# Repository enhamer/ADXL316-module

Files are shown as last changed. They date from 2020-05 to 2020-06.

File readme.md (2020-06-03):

<!---
#**============================================================================
#**
#**                    Accelerometer ADXL316 MODULE
#**                  THIS REPOSITORY IS PART OF THE ENHAMER
#**
#** TITLE:           ADXL-316 PCB (Circuit, Hardware)
#**
#** AUTHOR:          Marcin J. Kraśny
#**
#**					 Advanced Biological Imaging Laboratory
#**                  School of Physics
#**                  College of Science and Engineering
#**                  National University of Ireland, Galway
#**
#** SOURCE URL       https://github.com/enhamer/enhamer
#** COPYRIGHT        © 2015-2020 M.J.Kraśny
#** LICENSE          CERN-OHL-P v2
#** CREDITS          NEMESIS - Novel Energy Materials, Engineering Science 
#**                  and Integrated Systems
#**                  Department of Mechanical Engineering
#**					 University of Bath, UK
#**
#**============================================================================
#**============================================================================
-->

# ADXL316 module
Part of:
**Energy Harvesting Measurement Rig (ENHAMER)**

*A System for Characterisation of Piezoelectric Materials and Associated Electronics for Vibration Powered Energy Harvesting Devices*

>For detailed **Information, Manuals and Description** please go to [**ENHAMER**](https://github.com/enhamer/enhamer/).

Assembled module mounted on acrylic holder:
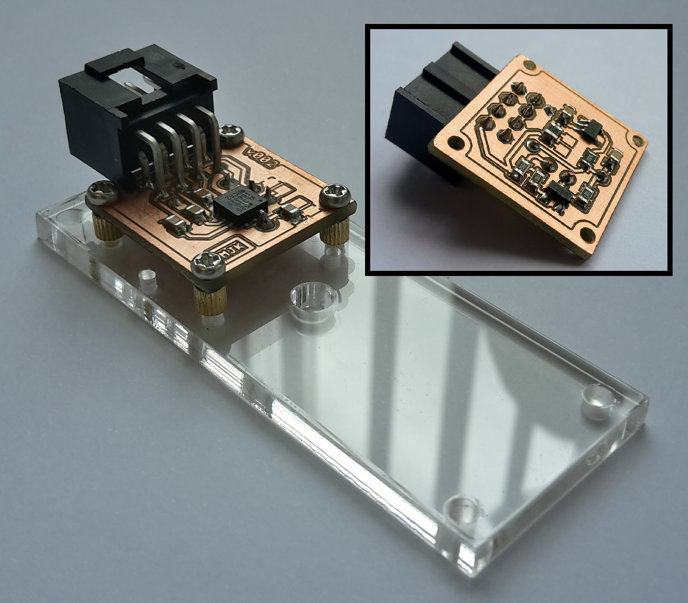
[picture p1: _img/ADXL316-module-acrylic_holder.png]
ADXL316 module


## Design software used
[EAGLE CAD](https://www.autodesk.com/products/eagle/overview)

# License
Copyright © 2015-2020 Marcin J. Kraśny

This work is licensed under the [CERN-OHL-P v2](LICENSE/cern_ohl_p_v2.txt); 
[CERN Open Hardware Licence version 2](https://cern.ch/cern-ohl).

You may redistribute and modify this documentation and make products
using it under the terms of the CERN-OHL-P v2 (<https:/cern.ch/cern-ohl>).
This documentation is distributed WITHOUT ANY EXPRESS OR IMPLIED WARRANTY INCLUDING OF MERCHANTABILITY, SATISFACTORY QUALITY AND FITNESS FOR A PARTICULAR PURPOSE. 
Please see the CERN-OHL-P v2 for applicable conditions.

# SOURCE
[https://github.com/enhamer](https://github.com/enhamer/enhamer/)

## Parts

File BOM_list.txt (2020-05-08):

Partlist

Exported from ADXL316-module.brd at 08/05/2020 17:02

EAGLE Version 9.5.1 Copyright (c) 1988-2019 Autodesk, Inc.

Assembly variant: 

Part     Value             Package          Library                Position (mil)        Orientation

ACC      ADXL316           QFN24-4X4_MJK    _Accelerometers_Krasny (522 390)             R270
C1       100nF             0805             _passive_Krasny        (675 519)             R0
C2       33pF              0805             _passive_Krasny        (675 603)             R0
C3       10nF              0805             _passive_Krasny        (420 141)             R180
C4       10nF              0805             _passive_Krasny        (420 243)             R180
C5       10nF              0805             _passive_Krasny        (339 342)             R180
C6       1uF               0805             _passive_Krasny        (369 213)             MR270
C7       1uF               0805             _passive_Krasny        (663 279)             MR270
L1       2u2H              0805             _passive_Krasny        (450 372)             MR270
R1       ns_0R             0805             _passive_Krasny        (369 372)             MR270
R2       0R                0805             _passive_Krasny        (570 372)             MR90
R3       1k                0805             _passive_Krasny        (450 645)             MR90
R4       20k               0805             _passive_Krasny        (369 645)             MR90
R5       1k                0805             _passive_Krasny        (663 561)             MR270
R6       ns_0R             0805             _passive_Krasny        (483 621)             R0
SV1                        MA04-2           con-lstb               (147.47244 392.15748) MR90
T1       BC847             SOT23            transistor             (550 641)             MR180
U1       ADP151AUJZ-3.3-R7 SOT95P280X100-5N _PowerSupply_Krasny    (504 207)             MR180

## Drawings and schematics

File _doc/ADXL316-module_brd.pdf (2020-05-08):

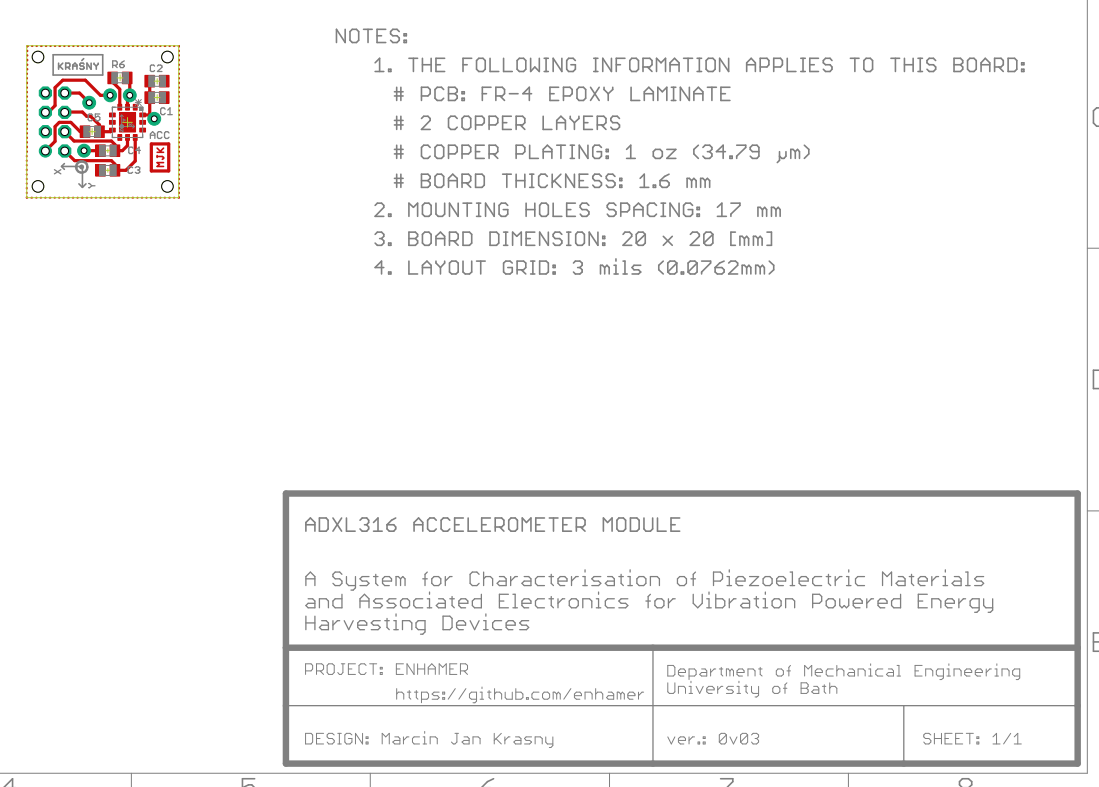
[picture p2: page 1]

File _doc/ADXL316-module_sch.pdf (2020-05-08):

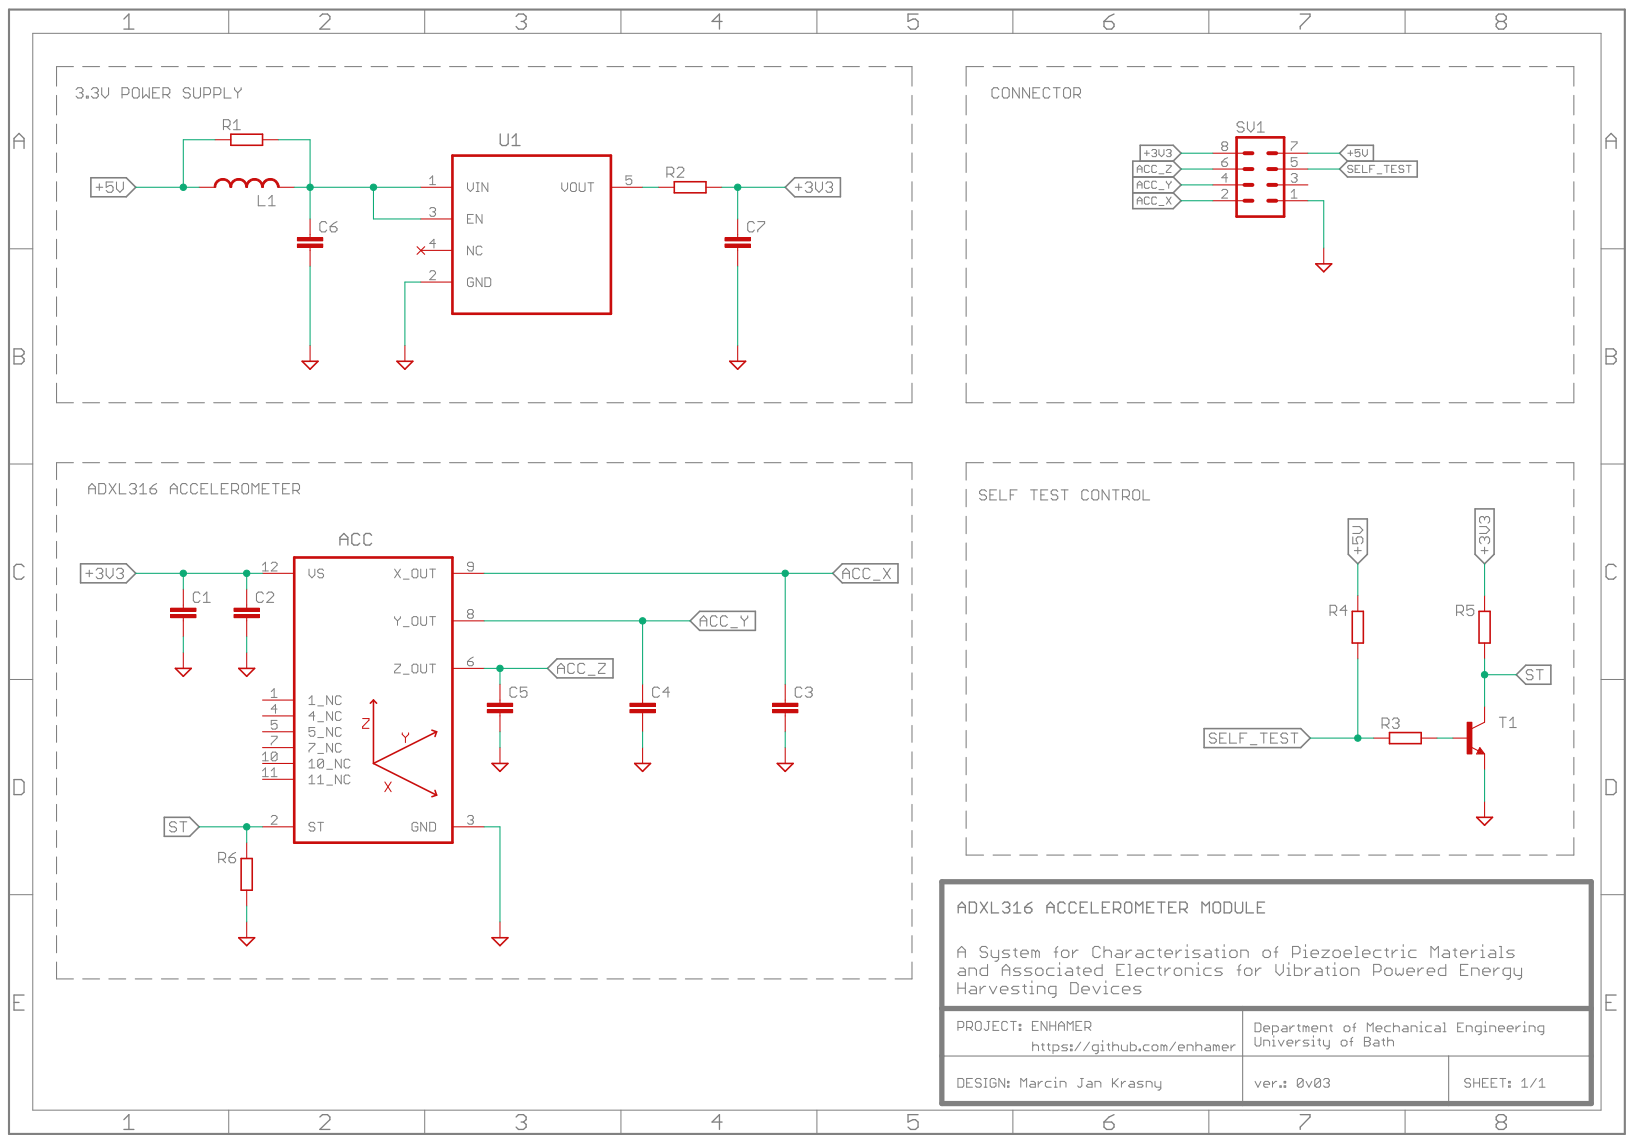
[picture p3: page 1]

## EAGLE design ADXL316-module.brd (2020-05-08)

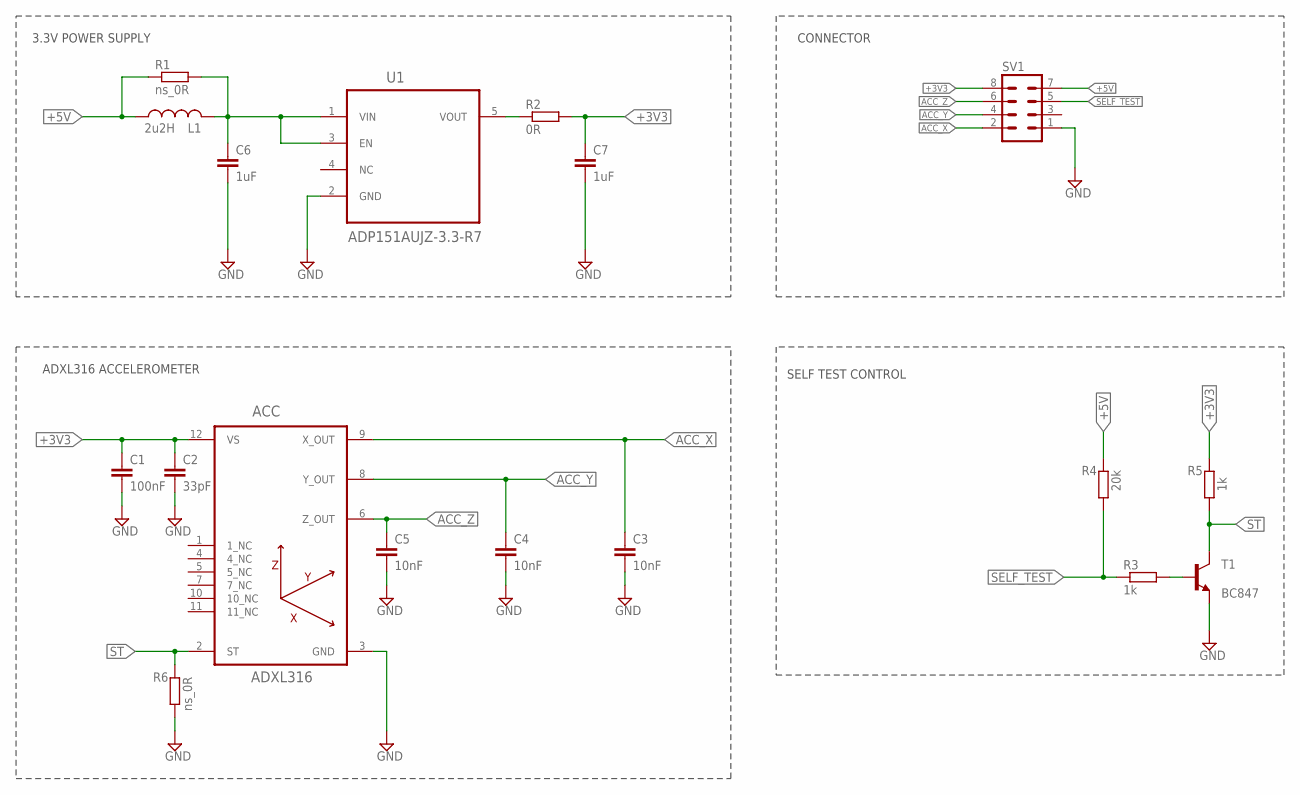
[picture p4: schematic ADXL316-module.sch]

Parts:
ACC: ADXL316; QFN24-4X4_MJK
C1: 100nF; 0805
C2: 33pF; 0805
C3, C4, C5: 10nF; 0805
C6, C7: 1uF; 0805
L1: 2u2H; 0805
R1, R6: ns_0R; 0805
R2: 0R; 0805
R3, R5: 1k; 0805
R4: 20k; 0805
SV1: MA04-2
T1: BC847; SOT23
U1: ADP151AUJZ-3.3-R7; SOT95P280X100-5N

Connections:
+3V3: ACC.12 (VS), C1.1, C2.1, C7.1, R2.2, R5.2, SV1.8
+5V: L1.1, R1.1, R4.2, SV1.7
ACC_X: ACC.9 (X_OUT), C3.1, SV1.2
ACC_Y: ACC.8 (Y_OUT), C4.1, SV1.4
ACC_Z: ACC.6 (Z_OUT), C5.1, SV1.6
GND: ACC.3 (GND), C1.2, C2.2, C3.2, C4.2, C5.2, C6.2, C7.2, R6.1, SV1.1, T1.2 (E), U1.2 (GND)
unnamed: C6.1, L1.2, R1.2, U1.1 (VIN), U1.3 (EN)
unnamed: R2.1, U1.5 (VOUT)
unnamed: R3.2, T1.1 (B)
SELF_TEST: R3.1, R4.1, SV1.5
ST: ACC.2 (ST), R5.1, R6.2, T1.3 (C)

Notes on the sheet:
CONNECTOR
3.3V POWER SUPPLY
SELF TEST CONTROL
ADXL316 ACCELEROMETER

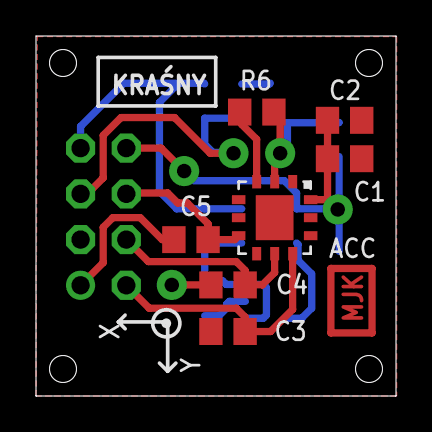
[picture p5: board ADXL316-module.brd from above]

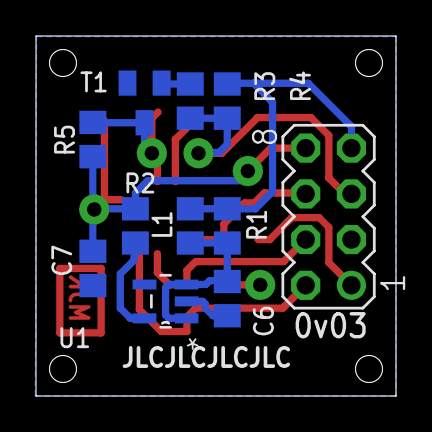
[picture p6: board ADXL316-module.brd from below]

Board: 2 copper layers, 20.0 x 20.0 mm, 18 parts (11 on the bottom side), 11 nets.
